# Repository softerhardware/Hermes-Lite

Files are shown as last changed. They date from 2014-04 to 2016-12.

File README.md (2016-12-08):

Hermes-Lite 1.x Deprecated Project!!!
=====================================

This project is deprecated. Current development is now focussed on the Hermes-Lite 2.x. See the main [Hermes-Lite Web Page](http://www.hermeslite.com) for the latest links and details.

## Introduction

The hardware is based on Analog Devices' [AD9866](http://www.analog.com/en/broadband-products/broadband-codecs/ad9866/products/product.html) which is a 12-bit broadband modem mixed signal front end that has been repurposed as a direct down conversion and direct up conversion SDR transceiver covering 0-36 MHz. A hardware prototype has been built and tested that uses a [BeMicro SDK](http://www.arrownac.com/solutions/bemicro-sdk/) FPGA board for DSP processing. The FPGA firmware is a port of the [Hermes SDR](http://openhpsdr.org/wiki/index.php?title=HERMES) project. The ported firmware preserves enough compatibility with the original Hermes SDR so that existing Hermes front-end software may be used with the Hermes-Lite without modification. Initial receive and transmit tests show good performance and appear later in this README. All software and hardware intellectual property is open source. Contributions and derivatives are encouraged. Please follow the standard ["Fork and Pull"](https://help.github.com/articles/using-pull-requests/) model and introduce yourself on [Google Groups](https://groups.google.com/forum/#!forum/hermes-lite).

#### Project Goals
 * 0-30MHz (HF) transceiver with decent performance
 * Entirely open source and open hardware design
 * Cost of less than $150 (cost includes FPGA board) for hobbyist who build their own
 * Maintain enough compatibility with Hermes to use existing Hermes SDR front-end software with no or minor modification

#### Hermes-Lite v1.21
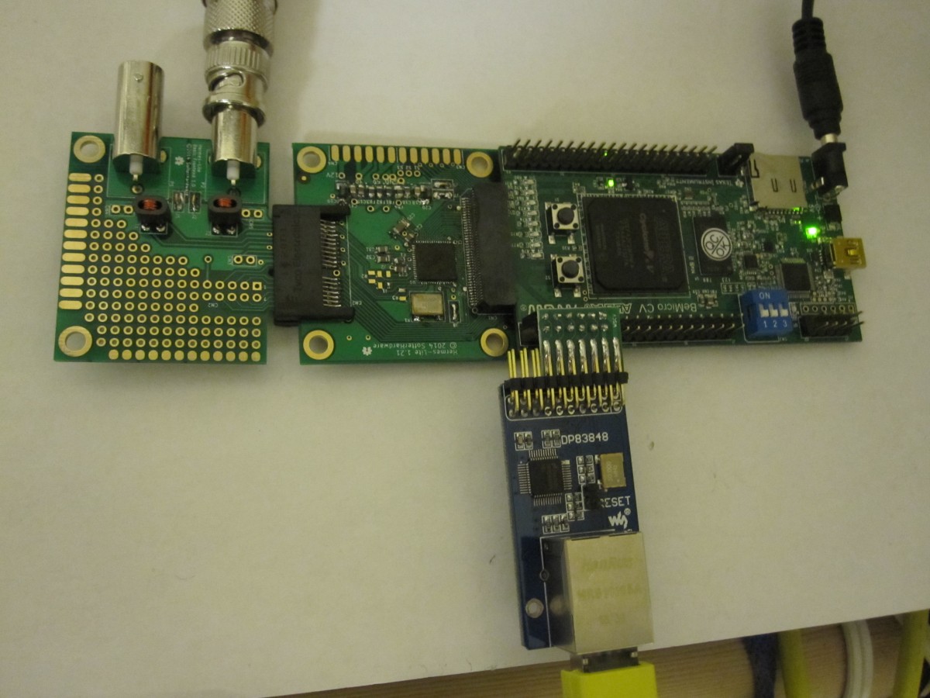
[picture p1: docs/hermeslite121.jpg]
Hermes-Lite121


#### Hermes-Lite v1.2
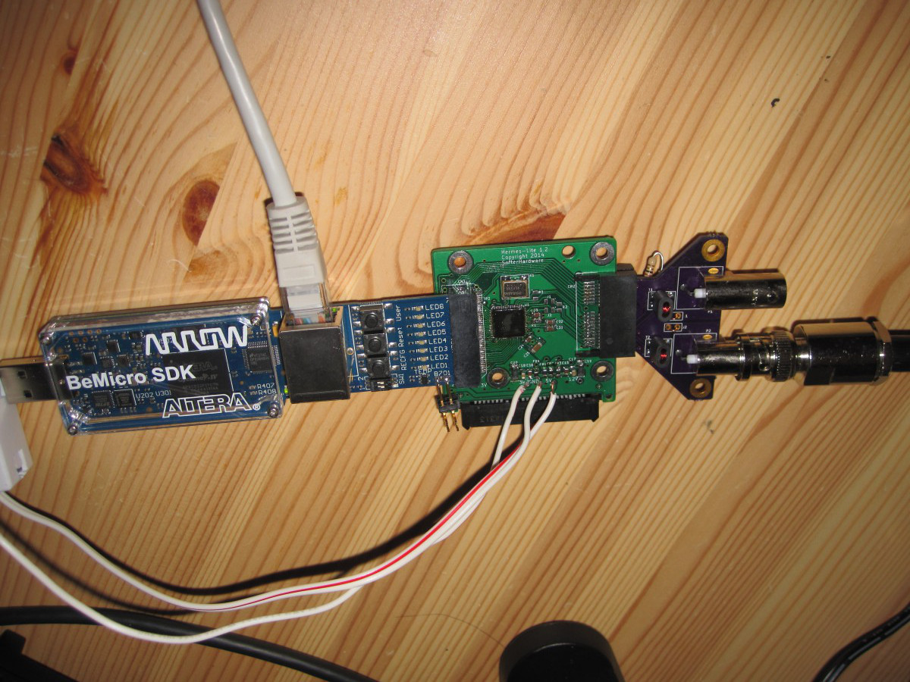
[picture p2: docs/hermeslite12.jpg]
Hermes-Lite12


#### Hermes-Lite v0.9
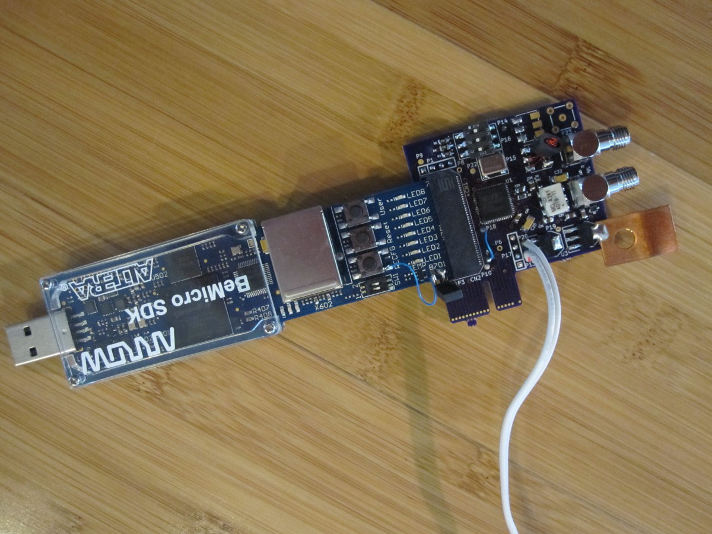
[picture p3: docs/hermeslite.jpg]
Hermes-Lite09


## Receive Experiments

I compared the Hermes-Lite with a Hermes and a [SoftRock RXTX Ensemble Transceiver](http://fivedash.com/) at spotting JT65 and JT9 transmissions with [WSJT-X](http://www.physics.princeton.edu/pulsar/K1JT/wsjtx.html) software running on Linux. I connected two radios to the same antenna right at a tee so there is no additional coax for either radio. I adjusted the radios so that common spots are within a few Hz. This ensures that one radio is not spotting signals that are out of band for the other. I adjusted audio levels to be similar for both copies of WSJT-X that I am running. WSJT-X is not very sensitive to different input levels anyway. The Hermes and Hermes-Lite were both using [ghpsdr-alex](http://napan.ca/ghpsdr3/index.php/Main_Page) software running on separate computers, and the RXTX was using [Quisk](http://james.ahlstrom.name/quisk/). The Hermes has a 4-1 impedance transformer. The Hermes-Lite has a 9-1 impedance transformer to better match the 400 Ohm input of the AD9866. This explains some differences in the data. The Hermes was run with no attenuation and hence has 20 dB gain from the LTC6400-20. The Hermes-Lite was also run with integrated gain set to ~20 dB unless noted otherwise. Finally, I let everything run for several hours to get a large sample set. 

### JT65 and JT9 Spot Data

| Band | 30M | 30M | 30M | 10M | 10M | 10M | 10M | 10M |
|:---- | ---:| ---:| ---:| ---:| ---:| ---:| ---:| ---:|
| Total Spots | 1629  |  676  |  826  |  2421  |  1488  |  1934  |  2461  |  570  |
| Common Spots | 1448 (88.9%)  |  647 (95.7%)  |  792 (95.9%)  |  1680 (69.4%)  |  778 (52.3%)  |  1420 (73.4%)  |  1663 (67.6%)  |  414 (72.6%)  |
| Lite Unique Spots |  |  22 (3.3%)  |  24 (2.9%)  |  |  699 (47.0%)  |  493 (25.5%)  |  768 (31.2%)  |  39 (6.8%)  |
| Hermes Unique Spots |  103 (6.3%)  |  7 (1.0%)  |  10 (1.2%)  |  342 (14.1%)  | |  21 (1.1%)  |  30 (1.2%)  |  117 (20.5%)  |
| RXTX Unique Spots | 78 (4.8%)  | | |  399 (16.5%)  |  11 (0.7%)  | | | |
| Lite Gain dB | | 20  | 28  | | 28  | 20  | 28  | 12  |
| Lite Common SNR Average dB |  |  -8.1 |  -7.7 | | -4.7 |  -9.0  |  -9.1 |  -12.8 |
| Hermes Common SNR Average dB | -7.3 |  -8.0 |  -7.7 |  -6.1 | |  -9.8 |  -10.2 |  -9.6 |
| RXTX Common SNR Average dB |  -7.5 | | |  -10.0 |  -12.6 |  | |  |
| Lite Unique SNR Average dB | |  -11.9 |  -11.5 |  |  -17.3 |  -16.2 |  -14.8 |  -15.5 |
| Hermes Unique SNR Average dB |  -15.3 |  -13.3 |  -20.4 |  -16.9 | |  -16.0 |  -14.2 |  -18.5 |
| RXTX Unique SNR Average dB |  -8.6 | | |  -11.9 |  -12.0 | | | |

The results from the Hermes-Lite compare well with the Hermes and the RXTX. You can see that on 30M all radios were about the same, maybe with a slight edge to the Hermes-Lite on unique spot count. The more interesting data is on 10M. Here there was a clear advantage to the Hermes-Lite in terms of unique spots and SNR (average SNR of all common spots) when the Hermes-Lite was run at 20 dB gain (to match the fixed gain of the Hermes but not accounting for the different input transformers) or 28 dB. When the Hermes-Lite was run with only 12 dB gain, the Hermes did better. This suggests that the Hermes might benefit from additional gain on the higher frequencies.  

When one radio has a unique spot that the other misses, it is not because the other radio missed all spots within that minute. Rather, I see that one radio spots n and the other n-1. The missed spot is not always the weakest signal. Sometimes it is a fairly strong signal. More often the missed spot is a JT9 signal, which has a narrower bandwidth and more stringent demands.

I did not experience problems with exceeding the lower dynamic range of the Hermes-Lite. This may be due in part to my relatively poor antenna setup and rural town location. All experiments were with a ~7M vertical with base at ~2M above ground with a wire grape trellis as a ground plane. The vertical was tuned with a Z-match at the base. Also, the integrated gain in the Hermes-Lite with control in 1 dB steps from -12 dB to +48 dB appears useful to extend the dynamic range. There is a fast path to adjust this gain so that an AGC may be implemented.

These experiments only test a receiver's performance at decoding JT65 and JT9 in the real world, and other proper receiver measurments should be run, but I think they are somewhat indicative of a receiver's performance in general. Even though a less expensive ADC and clock source were used when compared to the Hermes, I did not see any dramatic penalty in reception of JT65 and JT9 spots. Instead, I saw cases where the Hermes-Lite performed better. 

## Transmit Experiments

I tested transmit with [WSPR](http://www.physics.princeton.edu/pulsar/K1JT/wspr.html) and observed spots of my signal on [WSPRnet](http://wsprnet.org/). [PowerSDR](http://openhpsdr.org/wiki/index.php?title=PowerSDR) running under Windows was used to test transmit. At first, I had only 10 dBm (10 mW) output as I had not adjusted the transmit interpolation filter for the new sampling frequency. After adjusting the interpolation filter, I had 17 dBm (50 mW) output. I am using the IAMP on the AD9866 which will do 20 dBm (100 mW) and even 23 dBm (200 mW) with some distortion. I am targeting 20 dBm (100 mW) but need to get a large ferrite core to accomodate the correct turns ratio. The unique WSPR spots appear below. This is just an indicator that transmit is working and proper transmit measurments still must be made. 

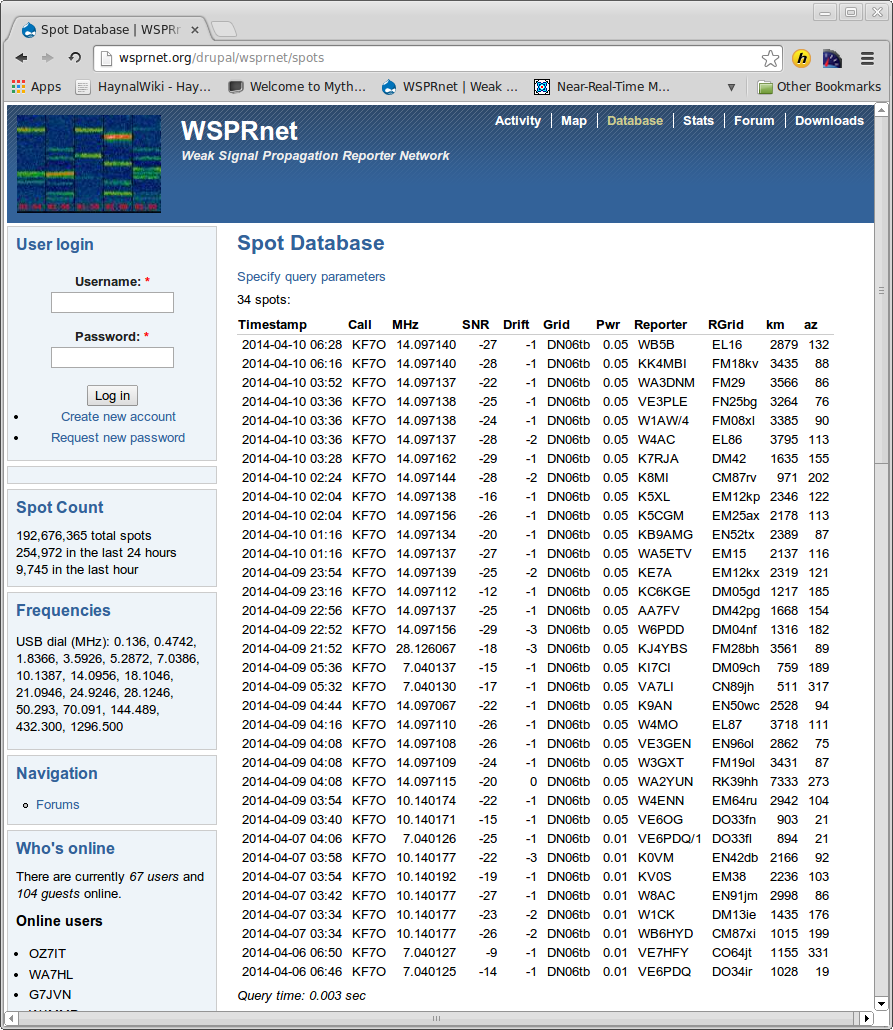
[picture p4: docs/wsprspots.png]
WSPR Spots


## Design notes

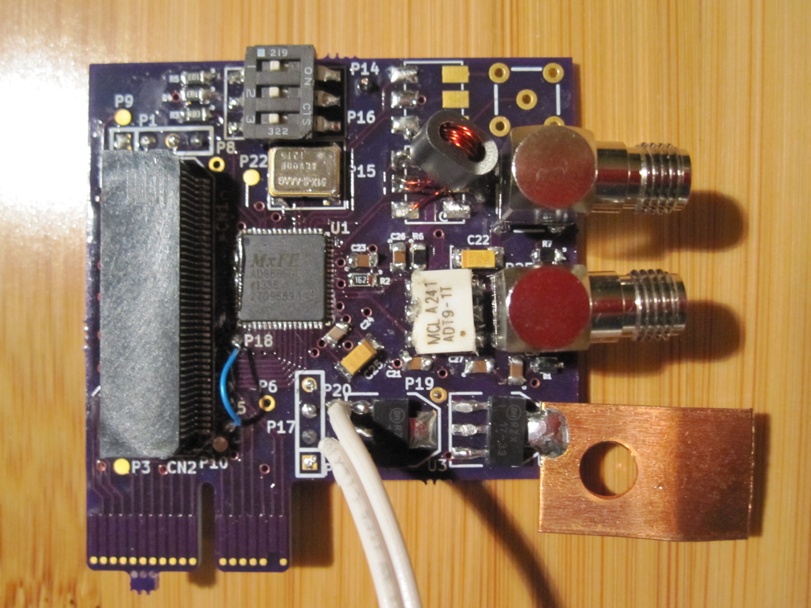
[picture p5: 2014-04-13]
pcb/hermeslite_front.jpg

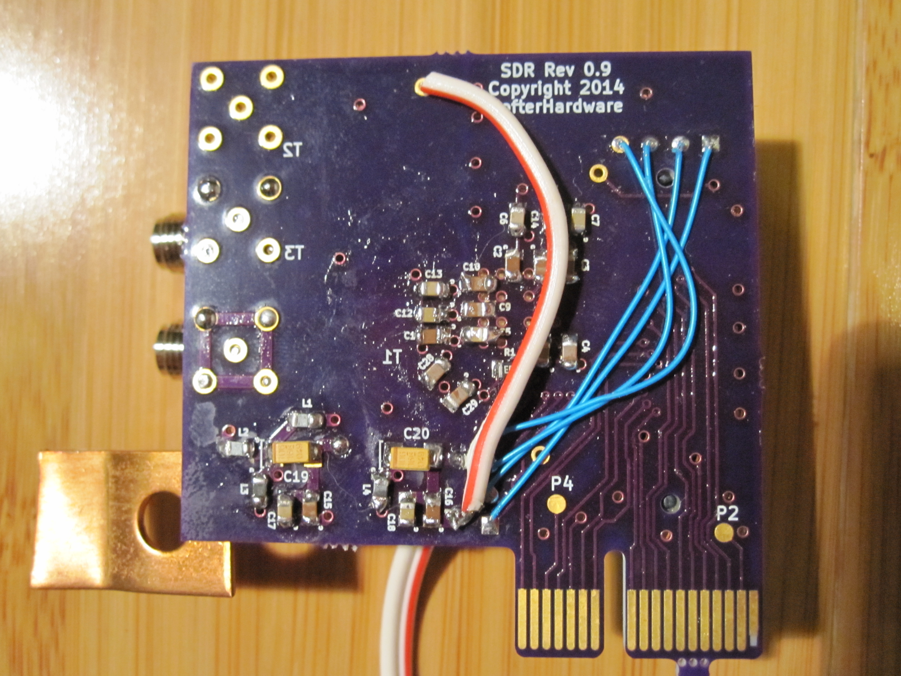
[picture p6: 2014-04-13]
pcb/hermeslite_back.jpg

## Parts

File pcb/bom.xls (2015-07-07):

Line Item | Quantity | Designator | Value/Description | Package | Type | Manufacturer | Manufacturer P/N | Substitution Allowed | Comments | Supplier | Supplier P/N | Supplier Price | Total Price
1 | 1 | U1 | AD9866BCPZ | 64 LFCSP | SMT | Analog Devices | AD9866BCPZ | No |  | Verical | AD9866BCPZ-ND | 27.457 | 27.46
2 | 20 | C1,C2,C3,C4,C9,C10,C11,C15,C16,C22,C23,C24,C28,C29,C31,C32,C33,C34,C35,C36 | 0.1 uF | 0805 | SMT | Yageo | CC0805ZRY5V9BB104 | Yes | Low ESR | Digi-Key | 311-1361-1-ND | 0.022 | 0.44
3 | 13 | C5,C6,C7,C8,C12,C13,C14,C17,C18,C21,C26,C27,C30 | 1 uF | 0805 | SMT | Yageo | CC0805KKX7R7BB105 | Yes | Low ESR | Digi-Key | 311-1365-1-ND | 0.052 | 0.67
4 | 2 | C19,C20 | 10 uF | 1206 | SMT | AVX Corporation | F931A106MAA | Yes | Low ESR | Digi-Key | 478-8193-1-ND | 0.279 | 0.56
5 | 1 | C25 | 10 uF | 1206 | SMT | Kemet | C1206C106Z8VACTU | Yes | Low ESR | Digi-Key | 399-1299-1-ND | 0.132 | 0.13
6 | 8 | FB1,FB2,FB3,FB4,FB5,FB6,FB7,FB8 | Ferrite Chip | 0805 | SMT | TDK Corporation | MPZ2012S221A | Yes |  | Digi-Key | 445-1568-1-ND | 0.101 | 0.81
7 | 1 | X1 | 73.728 Mhz XTAL | 6-SMD | SMT | Silicon Laboratories Inc | 510CCB-AAAG | No | Program to 73.728 Mhz | Digi-Key | 510CCB-AAAG-ND | 4.840 | 4.84
8 | 1 | R1 | 1.6 K | 0805 | SMT | Yageo | RC0805JR-071K6L | Yes |  | Digi-Key | 311-1.6KARCT-ND | 0.018 | 0.02
9 | 2 | J3,J6 | 0 Ohm | 0805 | SMT | Yageo | RC0805JR-070RL | Yes |  | Digi-Key | 311-0.0ARCT-ND | 0.018 | 0.04
10 | 1 | CN1 | BeMicro Connector |  | SMT | Samtec Inc | MEC6-140-02-L-D-RA1 | No |  | Samtec | MEC6-140-02-L-D-RA1 | 6.440 | 6.44
11 | 1 | CN2 | PCIe Connector |  | SMT | Sullins Connector Solutions | GWE18DHRN-T9410 | See Comments | Also TE Connectivity 5-1734857-5 | Digi-Key | S9649-ND | 2.620 | 2.62
12 | 2 | J5, J8 | Copper Wire |  | TH |  |  | Yes |  |  |  | 0.000 | 0.00
13 | 1 | U2 | SPI Serial EEPROM | SOT-23-6 | SMT | Microchip Technology | 25AA02E48T-I/OT | Yes | Optional IP/MAC EEPROM | Digi-Key | 25AA02E48T-I/OTCT-ND | 0.47 | 0.47
14 | 2 | R2,R3 | 200 Ohm | 0805 | SMT | Yageo | RC0805JR-07200RL | Yes | Optional termination | Digi-Key | 311-200ARCT-ND | 0.018 | 0.04
15 | 2 | R4,R5 | 47 Ohm | 0805 | SMT | Yageo | RC0805JR-0747RL | Yes | Optional termination | Digi-Key | 311-47ARCT-ND | 0.018 | 0.04
16 | 3 | J1,J2,J4 | 0 Ohm | 0805 | SMT | Yageo | RC0805JR-070RL | Yes | Optional jumpers | Digi-Key | 311-0.0ARCT-ND | 0.018 | 0.05
17 | 2 | CN3,CN4 | 0.1 DIL Header |  |  |  |  | Yes |  |  |  | 0.000 | 0.00
18 | 1 | J7 | Copper Wire |  |  |  |  | Yes |  |  |  | 0.000 | 0.00
 | 64 |  |  |  |  |  |  |  |  |  |  |  | 44.62
 |  | DO NOT STUFF MARKED IN RED

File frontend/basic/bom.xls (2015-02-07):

Line Item | Quantity | Designator | Value/Description | Package | Type | Manufacturer | Manufacturer P/N | Substitution Allowed | Comments | Supplier | Supplier P/N | Supplier Price | Total Price
1 | 4 | C1,C2,C3,C4 | 0.1 uF | 0805 | SMT | Yageo | CC0805ZRY5V9BB104 | Yes | Low ESR | Digi-Key | 311-1361-1-ND | 0.022 | 0.09
2 | 1 | FB1 | Ferrite Chip | 0805 | SMT | TDK Corporation | MPZ2012S221A | Yes |  | Digi-Key | 445-1568-1-ND | 0.101 | 0.10
3 | 1 | R1 | 0 Ohm | 0805 | SMT | Yageo | RC0805JR-070RL | Yes | Select to limit TX current | Digi-Key | 311-0.0ARCT-ND | 0.018 | 0.02
4 | 1 | D1 | TVS Diode | SOD323 | SMT | Bourns Inc. | CDSOD323-T05LC | See Comments | May adjust to limit peak voltages | Digi-Key | CDSOD323-T05LCCT-ND | 0.910 | 0.91
5 | 2 | T1,T2 | BN-61-2402 |  | TH | Kits and Parts | BN-61-2402 | See Comments | May change to improve balun | Kits and Parts | BN-61-2402 | 0.700 | 1.40
6 | 2 | P1,P2 | BNC Connector | BNC | TH | Molex Inc. | 731000105 | Yes |  | Digi-Key | WM5524-ND | 1.480 | 2.96
7 | 2 | J1,J2 | Copper Wire Jumper |  |  |  |  |  |  |  |  | 0.000 | 0.00
 | 13 |  |  |  |  |  |  |  |  |  |  |  | 5.48

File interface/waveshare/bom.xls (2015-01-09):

Line Item | Quantity | Designator | Value/Description | Package | Type | Manufacturer | Manufacturer P/N | Substitution Allowed | Comments | Supplier | Supplier P/N | Supplier Price | Total Price
1 | 1 | CN1 | 12-pin connector |  | TH | Sullins Connector Solutions | PPTC062LFBN-RC | Yes | Can use 2 6-pin Arduino headers | Digi-Key | S7074-ND | 0.980 | 0.98
 | 1 |  |  |  |  |  |  |  |  |  |  |  | 0.98

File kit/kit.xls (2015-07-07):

Line Item | Quantity | Value/Description | Package | Type | Manufacturer | Manufacturer P/N | Supplier | Supplier P/N | Supplier Price | Total Price | Notes
1 | 25 | 0.1 uF | 0805 | SMT | Yageo | CC0805ZRY5V9BB104 | Digi-Key | 311-1361-1-ND | 0.012 | 0.29
2 | 14 | 1 uF | 0805 | SMT | Yageo | CC0805KKX7R7BB105 | Digi-Key | 311-1365-1-ND | 0.027 | 0.38
3 | 3 | 10 uF | 1206 | SMT | AVX Corporation | F931A106MAA | Digi-Key | 478-8193-1-ND | 0.279 | 0.84
4 | 2 | 10 uF | 1206 | SMT | Kemet | C1206C106Z8VACTU | Digi-Key | 399-1299-1-ND | 0.080 | 0.16
5 | 10 | Ferrite Chip | 0805 | SMT | TDK Corporation | MPZ2012S221A | Digi-Key | 445-1568-1-ND | 0.057 | 0.57
6 | 1 | 73.728 Mhz XTAL | 6-SMD | SMT | Silicon Laboratories Inc | 510CCB-AAAG | Digi-Key | 510CCB-AAAG-ND | 5.570 | 5.57
7 | 2 | 1.6 K | 0805 | SMT | Yageo | RC0805JR-071K6L | Digi-Key | 311-1.6KARCT-ND | 0.013 | 0.03
8 | 7 | 0 Ohm | 0805 | SMT | Yageo | RC0805JR-070RL | Digi-Key | 311-0.0ARCT-ND | 0.007 | 0.05
9 | 1 | PCIe Connector |  | SMT | Sullins Connector Solutions | GWE18DHRN-T9410 | Digi-Key | S9649-ND | 2.620 | 2.62
10 | 1 | SPI Serial EEPROM | SOT-23-6 | SMT | Microchip Technology | 25AA02E48T-I/OT | Digi-Key | 25AA02E48T-I/OTCT-ND | 0.388 | 0.39
11 | 3 | 200 Ohm | 0805 | SMT | Samsung | RC2012J201CS | Digi-Key | 1276-5514-1-ND | 0.015 | 0.05
12 | 5 | 47 Ohm | 0805 | SMT | Yageo | RC0805JR-0747RL | Digi-Key | 311-47ARCT-ND | 0.007 | 0.04
13 | 1 | TVS Diode | SOD323 | SMT | Bourns Inc. | CDSOD323-T05LC | Digi-Key | CDSOD323-T05LCCT-ND | 0.794 | 0.79
14 | 2 | BNC Connector | BNC | TH | Molex Inc. | 731000105 | Digi-Key | WM5524-ND | 1.342 | 2.68
15 | 13 | Shipping and Handling |  |  |  |  |  |  | 8.380 | 0.64
16 | 1 | AD9866BCPZ | 64 LFCSP | SMT | Analog Devices | AD9866BCPZ | Verical | AD9866BCPZ | 27.457 | 27.46
17 | 13 | Shipping and Handling |  |  |  |  |  |  | 19.040 | 1.46
18 | 1 | BeMicro Connector |  | SMT | Samtec Inc | MEC6-140-02-L-D-RA1 | Samtec | MEC6-140-02-L-D-RA1 | 6.440 | 6.44
19 | 13 | Shipping and Handling |  |  |  |  |  |  | 25.000 | 1.92
20 | 2 | BN-43-2402 |  | TH | Kits and Parts | BN-61-2402 | Kits and Parts | BN-61-2402 | 0.280 | 0.56
21 | 13 | Shipping and Handling |  |  |  |  |  |  | 4.330 | 0.33
22 | 1 | Hermes-Lite PCB |  |  | Elecrow |  | Elecrow |  | 2.614 | 2.61
23 | 1 | Basic Frontend PCB |  |  | Elecrow |  | Elecrow |  | 1.108 | 1.11
24 | 1 | Waveshare Swizzle PCB |  |  | Elecrow |  | Elecrow |  | 0.478 | 0.48
25 | 50 | Shipping and Handling |  |  |  |  |  |  | 31.590 | 0.63
26 | 1 | Assembly |  |  | Zelpro Solutions |  |  |  | 26.000 | 26.00
27 |  | Shipping and Handling |  |  |  |  |  |  | 0.000 | 0.00
28 | 1 | Packing Material |  |  | Aviditi | M432 | Amazon |  | 0.241 | 0.24
29 |  | Shipping and Handling |  |  |  |  |  |  | 0.000 | 0.00
30 | 1 | Kitting, Packaging, Mailing |  |  |  |  |  | Son | 5.000 | 5.00
31 | 1 | Margin |  |  |  |  |  |  | 15.000 | 15.00
32 | 1 | Financial fees |  |  |  |  |  | PayPal | 3.250 | 3.25 | Estimate
 |  |  |  |  |  |  |  |  |  | 107.61 | Total
 | 1 | Domestic First Class |  |  |  |  |  |  | 3.00 |  | Estimate
 | 1 | Priority Flat Rate |  |  |  |  |  |  | 5.95
 | 1 | International First Class |  |  |  |  |  |  | 13.00 |  | Estimate
 | 1 | International Priority Flat Rate |  |  |  |  |  |  | 24.75

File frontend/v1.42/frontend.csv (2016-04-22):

Quantity | Package | Value | Reference | Notes | Digikey
1 | BREAKOUT14 | RELAYCNT14 | CN2 | 2X7 0.1 inch pin header
9 | C_0805_HandSoldering | 100n | C9 C10 C7 C8 C5 C6 C12 C14 C15 | ceramic
2 | C_0805_HandSoldering | 120p | C18 | 5.00%
2 | C_0805_HandSoldering | 150p | C2 C16 | 5.00%
1 | C_0805_HandSoldering | 160p | C3 | 5.00%
2 | C_0805_HandSoldering | 100p | C4 C11 C17 | 5.00%
1 | C_0805_HandSoldering | 180p | C16 | 5.00%
1 | C_0805_HandSoldering | 75p | C1 | 5.00%
1 | C_0805_HandSoldering | FB | FB2 | Ferite chip, MPZ2012S221A | 445-15-1-ND
1 | EDGE | EDGE | CN1
6 | Measurement_Point_Round-TH_Small | TST | P7 P8 P5 P6 P10 P4
1 | PINHEAD1-2 | 12V | P1 | 2X1 0.1 inch pin header for 12 volt power (only needed if no 12V on main board)
1 | PSOP-18 | ULN2803 | U6 | Texas Instruments darlington array
1 | R_0805_HandSoldering | 10k | R3
2 | R_0805_HandSoldering | 1200 | R10 R15
2 | R_0805_HandSoldering | 22 | R12 R13
2 | R_0805_HandSoldering | 1000 | R5 R18
2 | R_0805_HandSoldering | 2200 | R9 R11
2 | R_0805_HandSoldering | 24 1/4W | R7 R8 | Panasonic ERJ-P06J240V, Output resistors need ¼ W or more for higher power designs | P24ADCT-ND
2 | R_0805_HandSoldering | 240n | L1 L2 | 240n inductor 0806, Murata air wound 5% LQW2BASR24J00L | 490-5670-1-ND
4 | R_0805_HandSoldering | 270n | L3 L6 L7 L8 | 270n inductor 0806, Murata air wound 5% LQW2BASR27J00L | 490-5671-1-ND
2 | R_0805_HandSoldering | 330n | L4 L5 | 330n inductor 0806, Murata air wound 5% LQW2BASR33J00L | 490-5672-1-ND
2 | R_0805_HandSoldering | 33 1% | R1 R2
2 | R_0805_HandSoldering | 330 1% | R14 R16
1 | R_0805_HandSoldering | 75 1% | R6
1 | R_0805_HandSoldering | 560 | R4
1 | SOD-123 | BZT52B12 | D2 | Zener diode SOD-123, 12 volt 5 %
1 | SOD323 | DIODESCH2 | D1 | TVS diode, CDSOD323-T05LC | CDSOD323-T05LCT-ND
1 | SOIC-8-N-PAD | OPA2674 | U3 | dual op amp, current feedback, SOIC-8, or substitute OPA2677 for higher power
1 | SOT89-3_Housing | FCX690B | Q1 | NPN transistor in SOT-89, high beta (200 - 300) preferred, but any will work
1 | TantalC_SizeT_EIA-3528 | 10u | C13 | Tantalum capacitor, 3528 metric, 20 volts
1 | TransfBN2402 | 1:1 | T2 | BN-43-2402 four turns bifilar (use more turns for BN-61-2402)
1 | TransfBN2402 | 8:1Z | T1 | MABA-010143-FLUX18 or homebrew (see 1.2 frontend)
1 | pe4259 | PE4259 | U2 | RF switch for transmit/receive to single SMA (optional; otherwise jumper P5 to P8, and P6 to P7) | 1046-1011-2-ND
2 | rfconnectorB | SMA/BNC/HDR | P2 P3 | SMA RF connector
 |  |  |  | Build Option 1. On-Board T/R switch: Mount PE4259 and P2 (antenna). Omit P3.
 |  |  |  | Build Option 2. Separate Rfin and Rfout: Mount P2 and P3. Omit PE4259. Jumper P5 to P8 and P6 to P7.
 |  |  |  | Build Option 3: There are different filter designs available on the Hermes-Lite group.
 |  |  |  | Build Option 4: Reduce R7 and R8 for higher power. See frontend.html.
 |  |  |  | Build Option 5: Replace the OPA2674 with the OPA2677 package PSO-8 for higher power output
 |  |  |  | The Tx filter design is by Claudio, IN3OTD / DK1CG
 |  |  |  | The Rx filter design is by Andrew, G4XZL

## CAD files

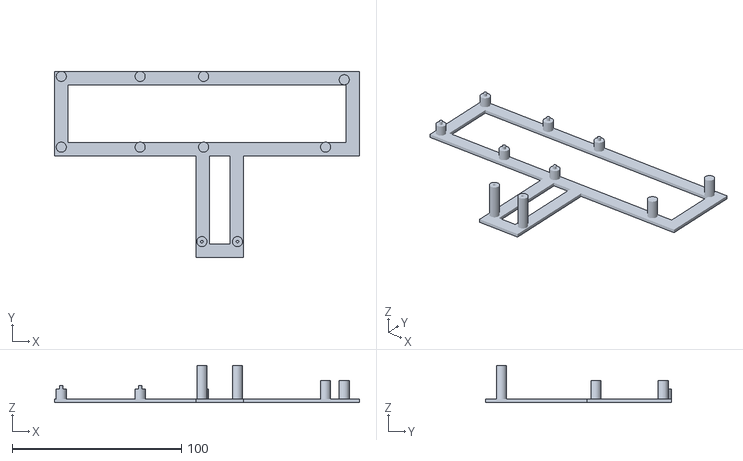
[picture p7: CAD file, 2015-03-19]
3Dprinter/hermes_lite_v2/hermes_lite_v2.stl
180.0 x 110.0 x 22.0

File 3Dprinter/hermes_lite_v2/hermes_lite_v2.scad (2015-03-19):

// main board size
L = 50;
W = 180;
T = 2;

// waveshare size, offset
Lw = 60;
Ww = 28;
Xw = 97.5;
ww = 21;
yw = 50.5;

B = 8;

// spacer heights
S1 = 6;
S2 = 11;
S3 = 20;
Ph = 2;

// spacer radii
Sr = 3;
Pr = 1.0;
Hr = 0.8;
$fn = 30;


module s1()
{
   cylinder(S1, r1=Sr, r2=Sr);
   translate([0,0,S1]) cylinder(Ph, r1=Pr, r2=Pr);
}

module s2()
{
   cylinder(S2, r1=Sr, r2=Sr);
}

module s3()
{
   difference() {
     cylinder(S3, r1=Sr, r2=Sr);
     translate ([0,0,3*S3/4]) cylinder(S3, r1=Hr, r2=Hr);
  }
}

module hermes_lite()

{

 difference() {
     cube([W,L,T]);
     translate ([B,B,0]) cube([W-2*B,L-2*B,T]);
 }
 difference() {
     translate ([Xw-Ww/2,-Lw,0]) cube([Ww,Lw,T]);
     translate ([Xw-Ww/2+B,-Lw+B,0]) cube([Ww-2*B,Lw-B,T]);
 }
 translate ([4,5.25,T] ) s1();
 translate ([4,47,T] ) s1();
 translate ([50.56,5.25,T] ) s1();
 translate ([50.56,47,T] ) s1();
 translate ([88,5.25,T] ) s1();
 translate ([88,47,T] ) s1();
 translate ([160,5.25,T]) s2();
 translate ([171,45,T]) s2();
 translate ([Xw-ww/2,-yw,T]) s3();
 translate ([Xw+ww/2,-yw,T]) s3();
}

hermes_lite();

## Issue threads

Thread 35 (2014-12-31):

Firmware: No 384kHz with new 61.44MHz crystal

softerhardware, 2014-12-31:
Hermes-Lite v1.2 and on use a 61.44MHz crystal for compatibility with future OpenHPSDR projects. Unfortunately, there is no simple divisor down to 384kHz for this frequency. The number of CIC filter decimation steps needs to be adjusted to support 384kHz

softerhardware, 2015-01-17:
Fixed in 20150115 release.

Closed 2015-01-17.

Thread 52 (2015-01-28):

Firmware: Software overload and ADC overload don't match

softerhardware, 2015-01-28:
See New Firmware 20150125 Released thread  on Google Groups.

softerhardware, 2015-03-09:
Fixed

Closed 2015-03-09.

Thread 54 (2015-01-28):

Firmware: AD9866 LPF hooked up to ALEX or J16 settings

softerhardware, 2015-01-28:

AC9HY, 2015-01-28:
Both of my amps have BPF or LPF on transmit. Since we have been seeing issues on the higher frequencies, I intend to built the first superband for 10/12 and 15/17 BPFs as the 2 pairs of bands. Will post info on the mailing list with progress. The Megaboard has a different TX filter config using LPFs. Progress on that board will be slower. Anyone can take the parameters for the 10M LPF from the current schematic and build a filter. I have enough spare components to be able to build one on a protoboard and send it to anyone that can test with it. Let me know.

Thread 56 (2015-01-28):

Firmware: Check Frequency Calibration/Computation

softerhardware, 2015-01-28:
There may have been a fix since I forked from 2.5a for this.

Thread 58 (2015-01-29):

Firmware: Noise floor numbers with 50 Ohm on RX are very different from v1.2

softerhardware, 2015-01-29:
This is due to gain changes when adjusting the filter stages.

softerhardware, 2015-03-09:
This is due to change in gain to match PowerSDR expectations.

Closed 2015-03-09.

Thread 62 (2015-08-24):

V2PA: Investigate heat sink options for enclosure.

AC9HY, 2015-08-24:

in3otd, 2015-12-10:
As briefly discussed [here] (https://groups.google.com/d/msg/hermes-lite/Zywnfl9dglg/Wk3YJk9QAgAJ) , Heatsink USA has a [4.23" wide heatsink] (http://www.heatsinkusa.com/4-230-wide-extruded-aluminum-heatsink/) that could be used in place of the end plate for the [proposed v2.0 enclosure] (https://github.com/softerhardware/Hermes-Lite/wiki/Hermes-Lite-2.0#form-factor-and-pcb) (the enclosure is approx. 4.27" wide). The holes for the fixing screws should end up nicely in the space between the fins.

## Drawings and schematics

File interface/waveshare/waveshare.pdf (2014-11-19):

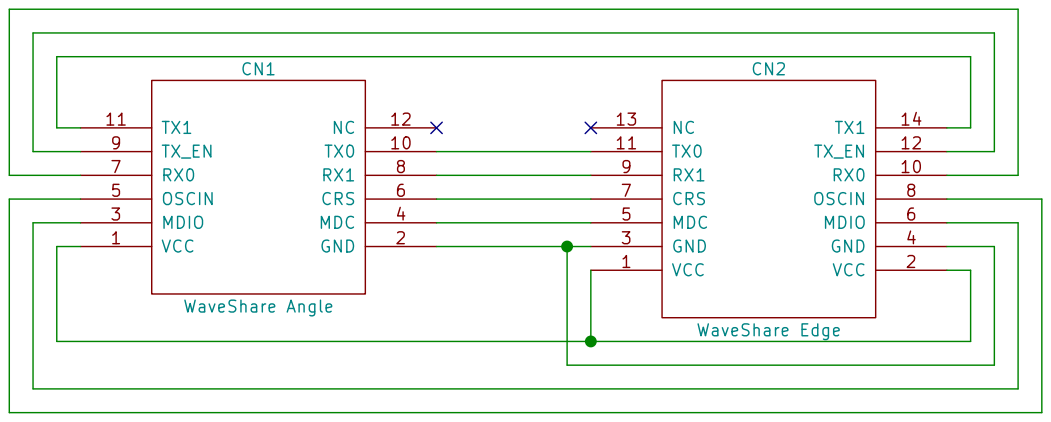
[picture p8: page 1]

File: waveshare.sch Sheet: / SofterHardware KF7O

Id: 1/1 Title: WaveShare Swizzle Board

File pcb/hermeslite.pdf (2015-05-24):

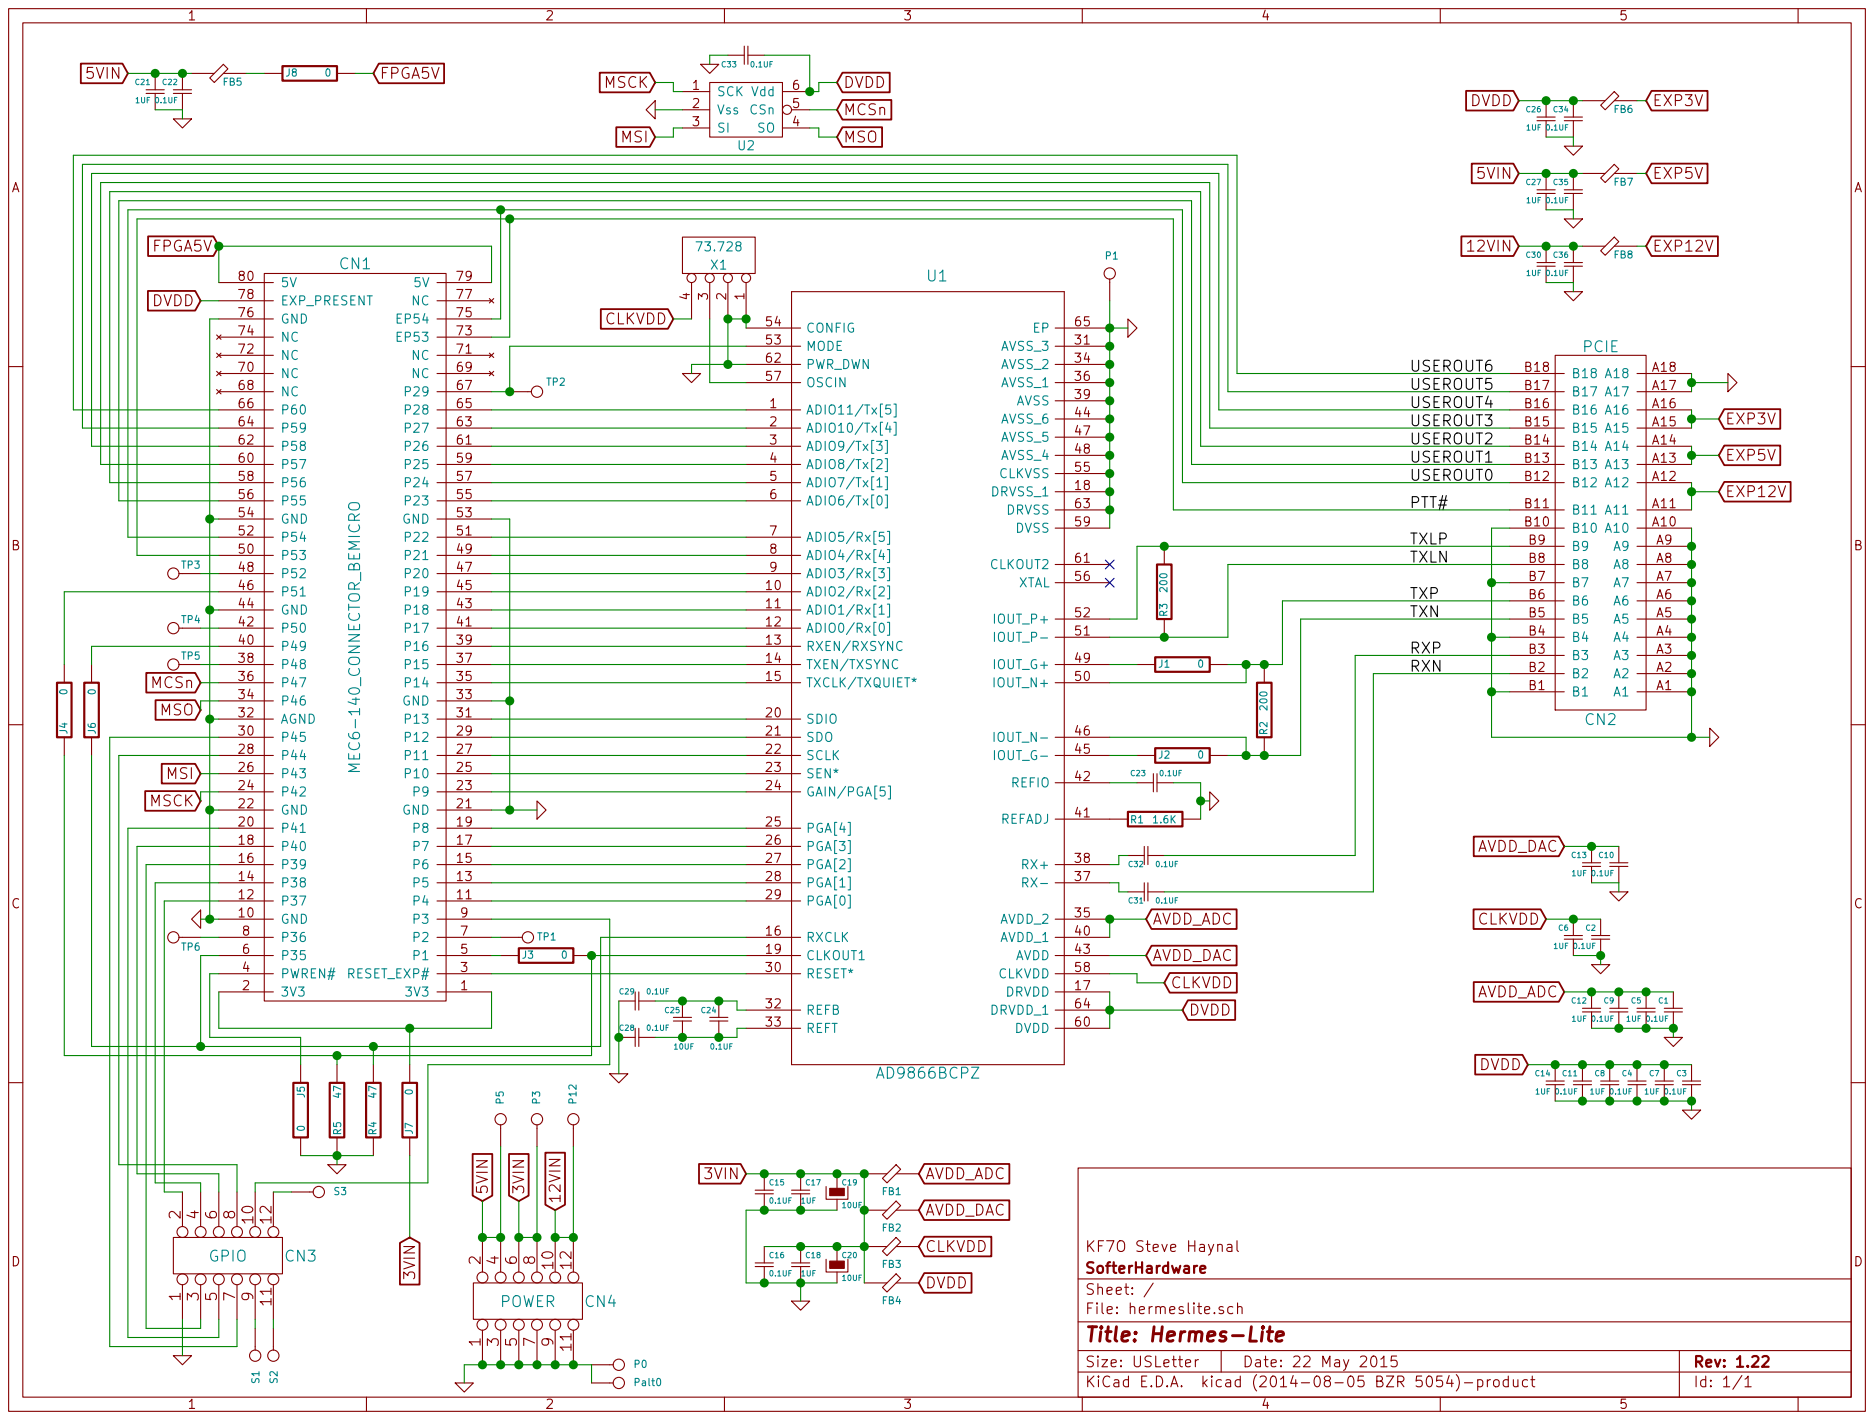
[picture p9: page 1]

File: hermeslite.sch Sheet: / SofterHardware KF7O Steve Haynal DVDD

Id: 1/1 Title: Hermes-Lite

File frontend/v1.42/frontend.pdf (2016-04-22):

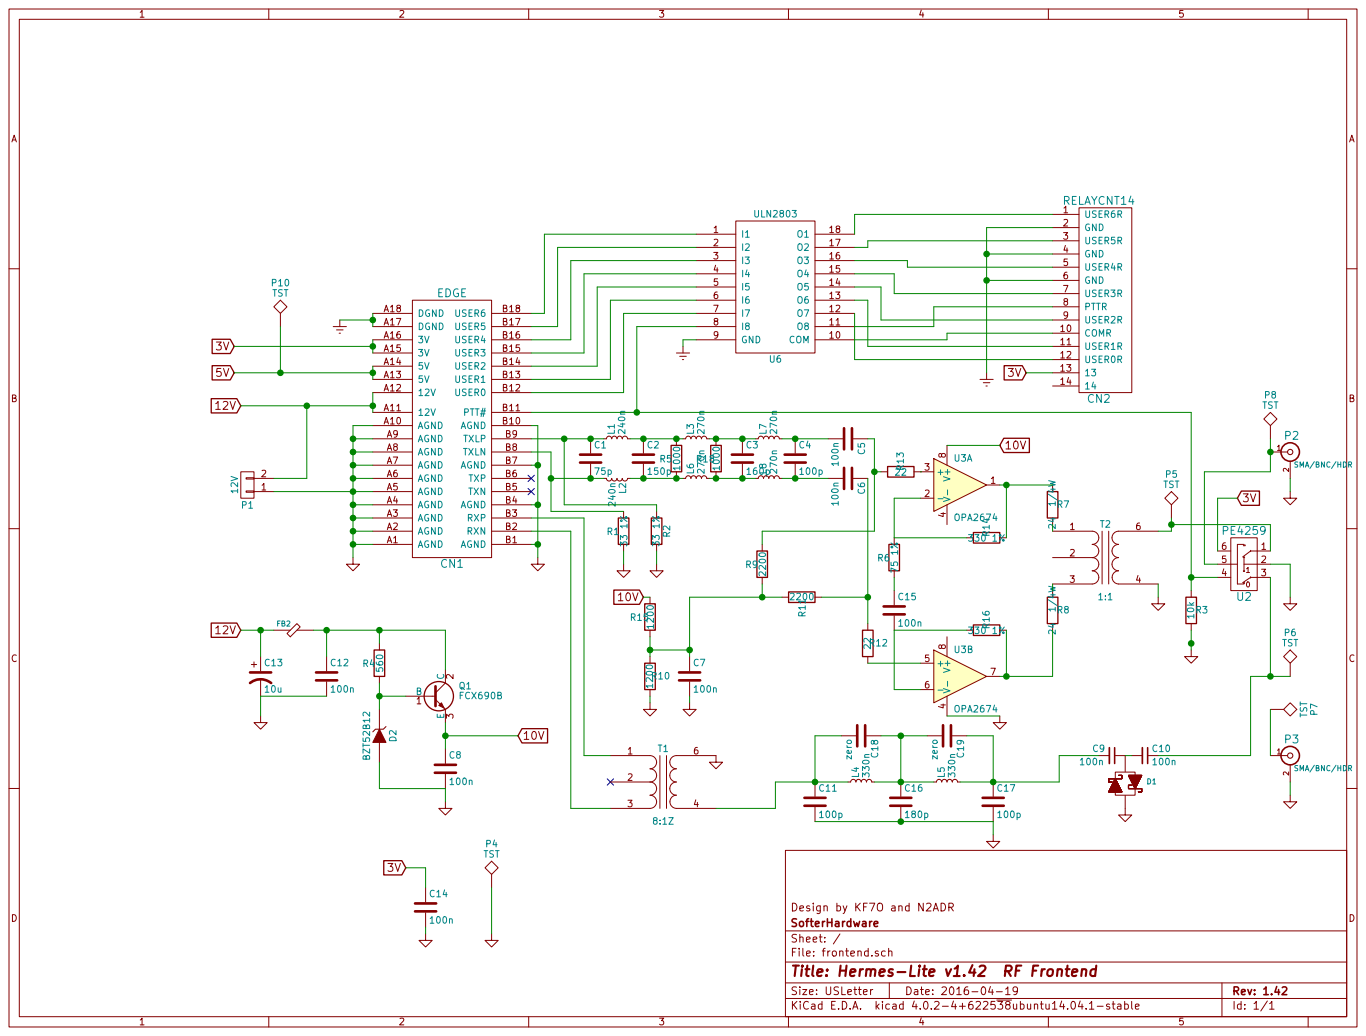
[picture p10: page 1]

File: frontend.sch Sheet: / SofterHardware Design by KF7O and N2ADR

Id: 1/1 Title: Hermes-Lite v1.42 RF Frontend

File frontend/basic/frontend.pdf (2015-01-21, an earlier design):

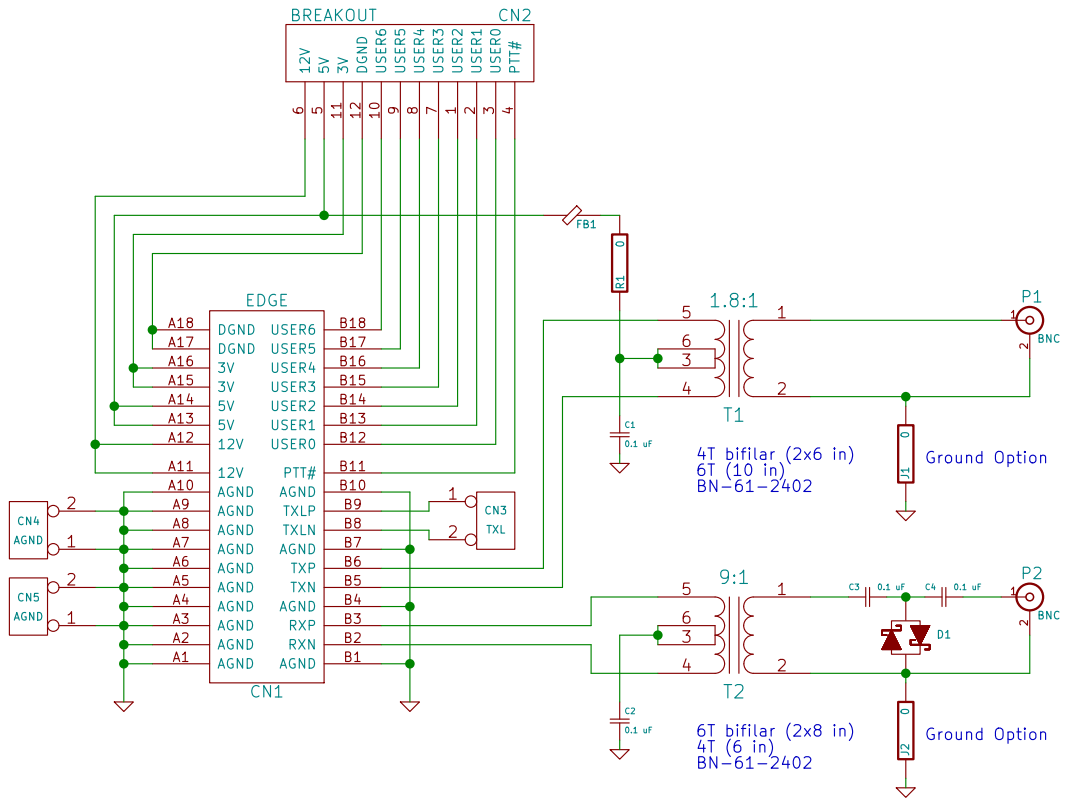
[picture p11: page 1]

File: frontend.sch Sheet: / SofterHardware KF7O

Id: 1/1 Title: Basic Hermes-Lite RF Frontend

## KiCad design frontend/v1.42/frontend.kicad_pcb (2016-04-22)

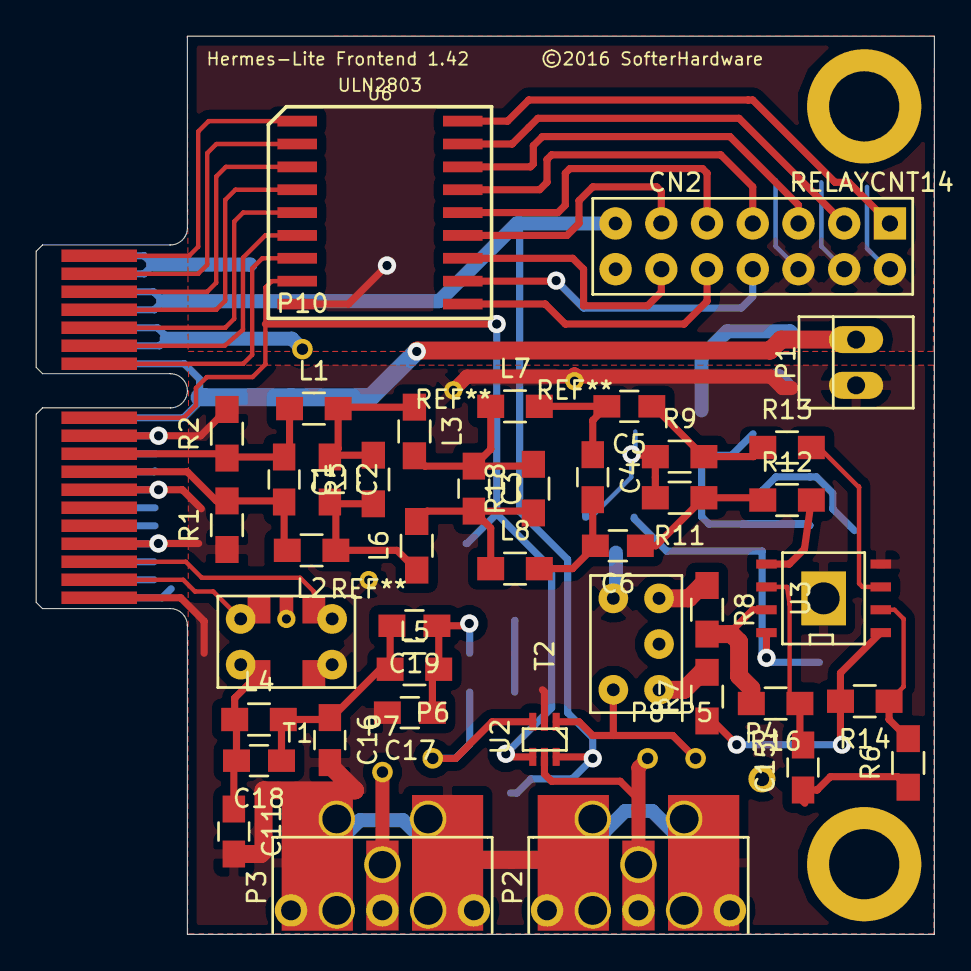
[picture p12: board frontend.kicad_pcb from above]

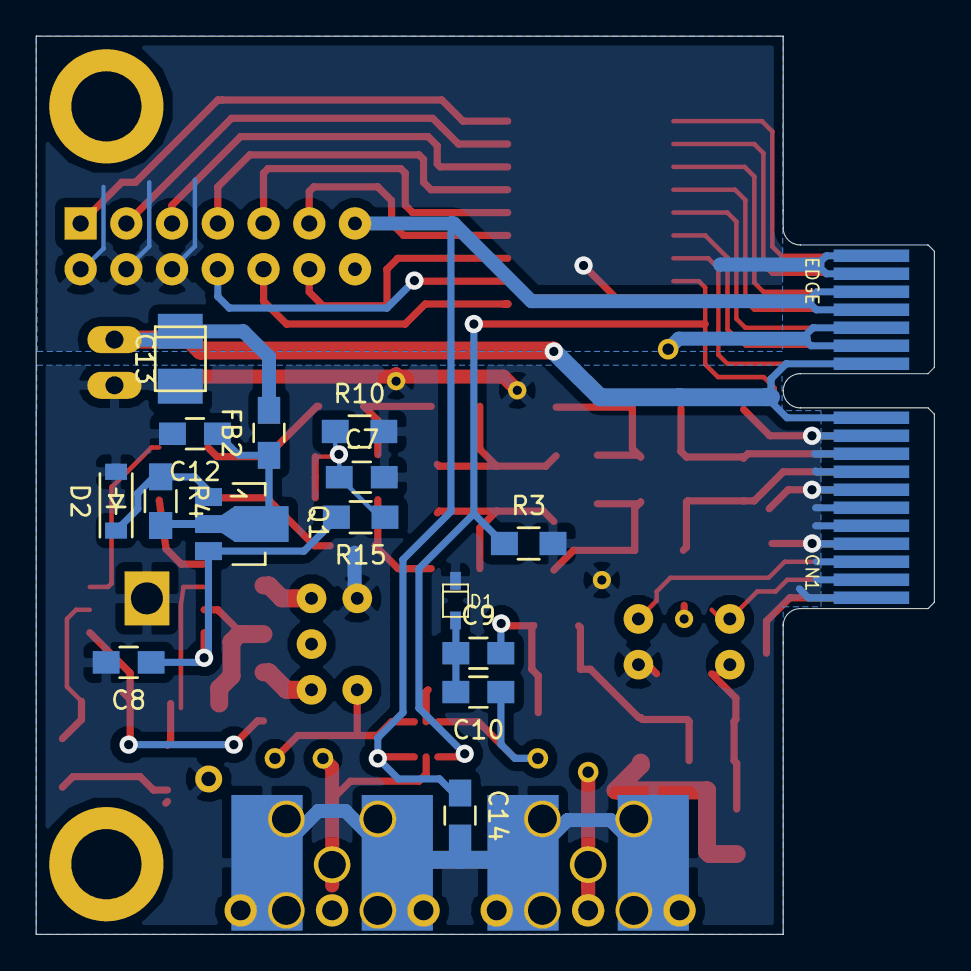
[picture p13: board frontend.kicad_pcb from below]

Board: 2 copper layers, 49.9 x 49.9 mm, 66 parts (16 on the bottom side), 55 nets.

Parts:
C1: 75p; C_0805_HandSoldering
C2: 150p; C_0805_HandSoldering
C3: 160p; C_0805_HandSoldering
C4, C11, C17: 100p; C_0805_HandSoldering
C5, C6, C7, C8, C9, C10, C12, C14, C15: 100n; C_0805_HandSoldering
C13: 10u; TantalC_SizeT_EIA-3528
C16: 180p; C_0805_HandSoldering
C18, C19: zero; C_0805_HandSoldering
CN1: EDGE
CN2: RELAYCNT14; BREAKOUT14
D1: DIODESCH2; SOD323
D2: BZT52B12; SOD-123
FB2: FB; C_0805_HandSoldering
L1, L2: 240n; R_0805_HandSoldering
L3, L6, L7, L8: 270n; R_0805_HandSoldering
L4, L5: 330n; R_0805_HandSoldering
MH: VAL**; MH
MH#2: VAL**; MH
P1: 12V; PINHEAD1-2
P2, P3: SMA/BNC/HDR; rfconnectorB
P4, P5, P6, P7, P8, P10: TST; Measurement_Point_Round-TH_Small
Q1: FCX690B; SOT89-3_Housing
R1, R2: 33 1%; R_0805_HandSoldering
R3: 10k; R_0805_HandSoldering
R4: 560; R_0805_HandSoldering
R5, R18: 1000; R_0805_HandSoldering
R6: 75 1%; R_0805_HandSoldering
R7, R8: 24 1/4W; R_0805_HandSoldering
R9, R11: 2200; R_0805_HandSoldering
R10, R15: 1200; R_0805_HandSoldering
R12, R13: 22; R_0805_HandSoldering
R14, R16: 330 1%; R_0805_HandSoldering
T1: 8:1Z; TransfBN2402
T2: 1:1; TransfBN2402
U2: PE4259; pe4259
U3: OPA2674; SOIC-8-N-PAD
U6: ULN2803; PSOP-18

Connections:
3V: C14.1, CN1.A15, CN1.A16, CN2.13, U2.6
5V: CN1.A13, CN1.A14, P10.1
10V: C8.1, Q1.3, R15.2, U3.8
12V: C13.1, CN1.A11, CN1.A12, FB2.2, P1.2
GND: C7.2, C8.2, C11.2, C12.2, C13.2, C14.2, C16.2, C17.2, CN1.A1, CN1.A2, CN1.A3, CN1.A4, CN1.A5, CN1.A6, CN1.A7, CN1.A8, CN1.A9, CN1.A10, CN1.B1, CN1.B4, CN1.B7, CN1.B10, D1.2, D2.2, P1.1, P2.2, P3.2, P4.1, R1.1, R2.2, R3.2, R10.2, T1.6, T2.4, U2.2, U3.4
GNDREF: CN1.A17, CN1.A18, CN2.2, CN2.4, CN2.6, U6.9
unnamed: C1.1, CN1.B9, L1.1, R2.1
unnamed: C1.2, CN1.B8, L2.2, R1.2
unnamed: C2.1, L1.2, L3.1, R5.2
unnamed: C2.2, L2.1, L6.1, R5.1
unnamed: C3.1, L3.2, L7.1, R18.2
unnamed: C3.2, L6.2, L8.1, R18.1
unnamed: C4.1, C5.2, L7.2
unnamed: C4.2, C6.2, L8.2
unnamed: C5.1, R9.2, R13.1
unnamed: C6.1, R11.1, R12.1
unnamed: C7.1, R9.1, R10.1, R11.2, R15.1
unnamed: C10.1, P6.1, U2.3
unnamed: C9.1, C10.2, D1.1
unnamed: C11.1, C18.2, L4.1, T1.4
unnamed: C12.1, FB2.1, Q1.2, R4.2
unnamed: C15.1, R6.1
unnamed: C15.2, R16.1, U3.6
unnamed: C16.1, C18.1, C19.2, L4.2, L5.1
unnamed: C9.2, C17.1, C19.1, L5.2
unnamed: CN1.B2, T1.3
unnamed: CN1.B3, T1.1
unnamed: CN1.B11, R3.1, U2.4, U6.8
unnamed: CN1.B12, U6.7
unnamed: CN1.B13, U6.6
unnamed: CN1.B14, U6.5
unnamed: CN1.B15, U6.4
unnamed: CN1.B16, U6.3
unnamed: CN1.B17, U6.2
unnamed: CN1.B18, U6.1
unnamed: CN2.1, U6.18
unnamed: CN2.3, U6.17
unnamed: CN2.5, U6.16
unnamed: CN2.7, U6.15
unnamed: CN2.8, U6.11
unnamed: CN2.9, U6.14
unnamed: CN2.10, U6.10
unnamed: CN2.11, U6.13
unnamed: CN2.12, U6.12
unnamed: D2.1, Q1.1, R4.1
unnamed: P2.1, P8.1, U2.5
unnamed: P3.1, P7.1
unnamed: P5.1, T2.6, U2.1
unnamed: R7.2, T2.1
unnamed: R8.1, T2.3
unnamed: R12.2, U3.5
unnamed: R13.2, U3.3
unnamed: R6.2, R14.1, U3.2
unnamed: R7.1, R14.2, U3.1
unnamed: R8.2, R16.2, U3.7

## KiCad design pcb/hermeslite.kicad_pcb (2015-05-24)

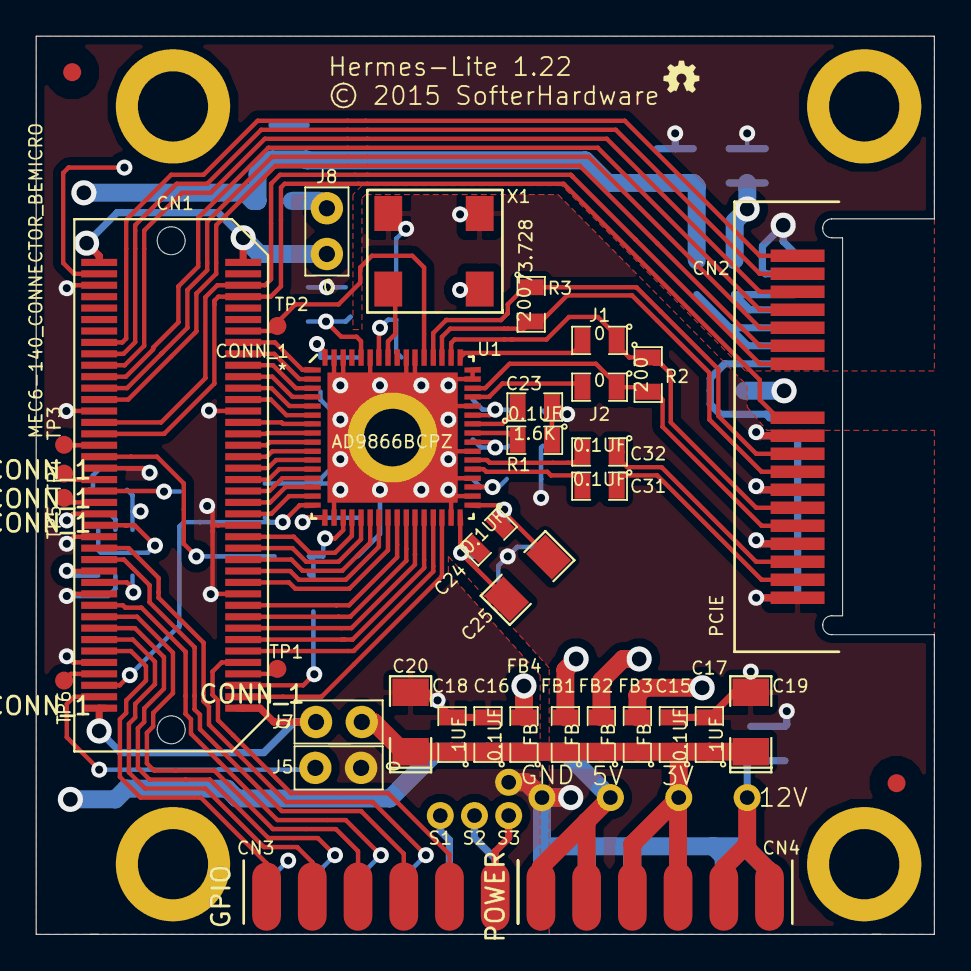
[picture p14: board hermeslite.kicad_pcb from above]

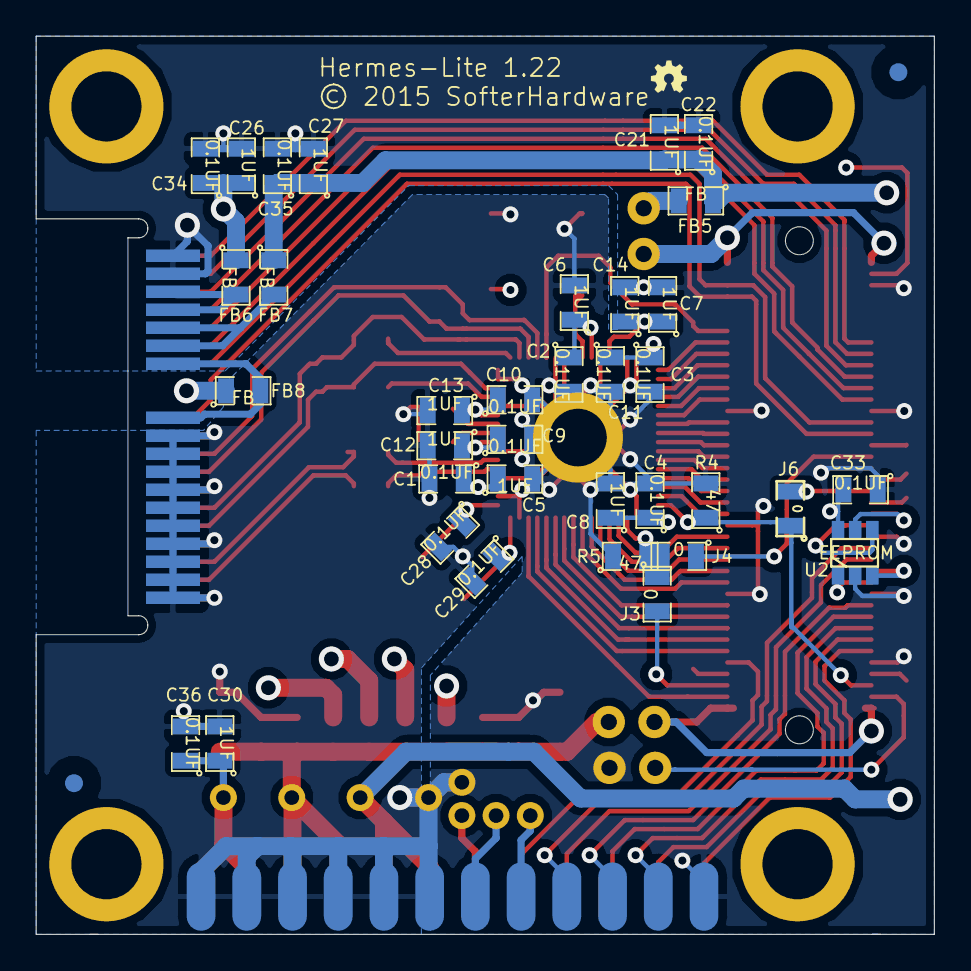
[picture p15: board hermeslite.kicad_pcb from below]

Board: 4 copper layers, 49.9 x 49.9 mm, 87 parts (37 on the bottom side), 90 nets.

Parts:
C1, C2, C3, C4, C9, C10, C11, C23, C24, C28, C29: 0.1UF; SM0805
C5, C6, C7, C8, C12, C13, C14: 1UF; SM0805
C15, C16, C22, C31, C32, C33, C34, C35, C36: 0.1UF; SMD-0805
C17, C18, C21, C26, C27, C30: 1UF; SMD-0805
C19, C20: 10UF; SMD-1206_Pol
C25: 10UF; SM1206
CN1: MEC6-140_CONNECTOR_BEMICRO; MEC6-140-02-X-D-RAX
CN2: PCIE; PCIESTRADDLE
CN3: GPIO; EDGE6
CN4: POWER; EDGE6
FB1, FB2, FB3, FB4, FB5, FB6, FB7, FB8: FB; SMD-0805
FIDUCIAL: VAL**; FIDUCIAL
FIDUCIAL#2, FIDUCIAL#3, FIDUCIAL#4: VAL**; FIDUCIAL
J1, J2, J3, J4, J6: 0; SMD-0805
J5, J7, J8: 0; JUMPER
MH: VAL**; MH
MH#2, MH#3, MH#4: VAL**; MH
P0, P3, P5, P12: CONN_1; Measurement_Point_Round-TH_Small
P1: CONN_1; TH
Palt0: CONN_1; Measurement_Point_Round-TH_Small
R1: 1.6K; SM0805
R2, R3: 200; SMD-0805
R4, R5: 47; SMD-0805
S1, S2, S3: CONN_1; Measurement_Point_Round-TH_Small
TP1, TP2, TP3, TP4, TP5, TP6: CONN_1; TP
U1: AD9866BCPZ; CP_64_3-M
U2: EEPROM; SOT-23-6
X1: 73.728; Si510

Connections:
3VIN: C15.1, C16.1, C17.1, C18.1, C19.1, C20.1, CN4.6, CN4.8, FB1.1, FB2.1, FB3.1, FB4.1, J7.2, P3.1
5VIN: C21.1, C22.1, C27.1, C35.1, CN4.2, CN4.4, FB5.1, FB7.1, P5.1
12VIN: C30.1, C36.1, CN4.10, CN4.12, FB8.1, P12.1
/PTT#: CN1.50, CN1.73, CN2.B11
/RXN: C31.1, CN2.B2
/RXP: C32.1, CN2.B3
/TXLN: CN2.B8, R3.2, U1.51
/TXLP: CN2.B9, R3.1, U1.52
/TXN: CN2.B5, J2.1, R2.2, U1.46
/TXP: CN2.B6, J1.1, R2.1, U1.50
/USEROUT0: CN1.52, CN1.75, CN2.B12
/USEROUT1: CN1.56, CN2.B13
/USEROUT2: CN1.58, CN2.B14
/USEROUT3: CN1.60, CN2.B15
/USEROUT4: CN1.62, CN2.B16
/USEROUT5: CN1.64, CN2.B17
/USEROUT6: CN1.66, CN2.B18
AVDD_ADC: C1.1, C5.1, C9.1, C12.1, FB1.2, U1.35, U1.40
AVDD_DAC: C10.1, C13.1, FB2.2, U1.43
CLKVDD: C2.1, C6.1, FB3.2, U1.58, X1.4
DVDD: C3.1, C4.1, C7.1, C8.1, C11.1, C14.1, C26.1, C33.2, C34.1, CN1.78, FB4.2, FB6.1, U1.17, U1.60, U1.64, U2.6
EXP3V: CN2.A15, CN2.A16, FB6.2
EXP5V: CN2.A13, CN2.A14, FB7.2
EXP12V: CN2.A11, CN2.A12, FB8.2
FPGA5V: CN1.79, CN1.80, J8.1
GND: C1.2, C2.2, C3.2, C4.2, C5.2, C6.2, C7.2, C8.2, C9.2, C10.2, C11.2, C12.2, C13.2, C14.2, C15.2, C16.2, C17.2, C18.2, C19.2, C20.2, C21.2, C22.2, C23.2, C26.2, C27.2, C28.2, C29.2, C30.2, C33.1, C34.2, C35.2, C36.2, CN1.10, CN1.21, CN1.22, CN1.32, CN1.33, CN1.44, CN1.53, CN1.54, CN1.76, CN2.A1, CN2.A2, CN2.A3, CN2.A4, CN2.A5, CN2.A6, CN2.A7, CN2.A8, CN2.A9, CN2.A10, CN2.A17, CN2.A18, CN2.B1, CN2.B4, CN2.B7, CN2.B10, CN3.1, CN4.1, CN4.3, CN4.5, CN4.7, CN4.9, CN4.11, J5.1, P0.1, P1.1, Palt0.1, R1.1, R4.2, R5.1, U1.18, U1.31, U1.34, U1.36, U1.39, U1.44, U1.47, U1.48, U1.54, U1.55, U1.59, U1.62, U1.63, U1.65, U2.2, X1.1, X1.2
MCSn: CN1.36, U2.5
MSCK: CN1.24, U2.1
MSI: CN1.26, U2.3
MSO: CN1.34, U2.4
unnamed: C23.1, U1.42
unnamed: C24.1, C25.1, C28.1, U1.33
unnamed: C24.2, C25.2, C29.1, U1.32
unnamed: C31.2, U1.37
unnamed: C32.2, U1.38
unnamed: CN1.1, CN1.2, J7.1
unnamed: CN1.3, U1.30
unnamed: CN1.4, J5.2
unnamed: CN1.5, J3.2
unnamed: CN1.6, J6.1, R4.1, U1.16
unnamed: CN1.7, TP1.1
unnamed: CN1.8, TP6.1
unnamed: CN1.9, CN3.10
unnamed: CN1.11, U1.29
unnamed: CN1.12, CN3.2
unnamed: CN1.13, U1.28
unnamed: CN1.14, CN3.4
unnamed: CN1.15, U1.27
unnamed: CN1.16, CN3.3
unnamed: CN1.17, U1.26
unnamed: CN1.18, CN3.6
unnamed: CN1.19, U1.25
unnamed: CN1.20, CN3.5
unnamed: CN1.23, U1.24
unnamed: CN1.25, U1.23
unnamed: CN1.27, U1.22
unnamed: CN1.28, CN3.8
unnamed: CN1.29, U1.21
unnamed: CN1.30, CN3.7
unnamed: CN1.31, U1.20
unnamed: CN1.35, U1.15
unnamed: CN1.37, U1.14
unnamed: CN1.38, TP5.1
unnamed: CN1.39, U1.13
unnamed: CN1.40, J6.2
unnamed: CN1.41, U1.12
unnamed: CN1.42, TP4.1
unnamed: CN1.43, U1.11
unnamed: CN1.45, U1.10
unnamed: CN1.46, J4.1
unnamed: CN1.47, U1.9
unnamed: CN1.48, TP3.1
unnamed: CN1.49, U1.8
unnamed: CN1.51, U1.7
unnamed: CN1.55, U1.6
unnamed: CN1.57, U1.5
unnamed: CN1.59, U1.4
unnamed: CN1.61, U1.3
unnamed: CN1.63, U1.2
unnamed: CN1.65, U1.1
unnamed: CN1.67, TP2.1, U1.53
unnamed: CN3.9, S1.1
unnamed: CN3.11, S2.1
unnamed: CN3.12, S3.1
unnamed: FB5.2, J8.2
unnamed: J1.2, U1.49
unnamed: J2.2, U1.45
unnamed: J3.1, J4.2, R5.2, U1.19
unnamed: R1.2, U1.41
unnamed: U1.57, X1.3

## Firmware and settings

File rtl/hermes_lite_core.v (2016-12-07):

//
//  Hermes Lite
// 
//
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
// (C) Phil Harman VK6APH, Kirk Weedman KD7IRS  2006, 2007, 2008, 2009, 2010, 2011, 2012, 2013, 2014 
// (C) Steve Haynal KF7O 2014, 2015, 2016

// New VNA mode added by James C. Ahlstrom, N2ADR, 1 December 2016

// This is a port of the Hermes project from www.openhpsdr.org to work with
// the Hermes-Lite hardware described at http://github.com/softerhardware/Hermes-Lite.
// It was forked from Hermes V2.5 but kept up to date to v3.1

module hermes_lite_core(

    input clk50mhz,
    input exp_present,
    input AD9866clkX1,

    input IF_clk,
    input ad9866spiclk,
    input rstclk,
    input EEPROM_clock,
    input IF_locked,

    input extreset,
    output [7:0] leds, 

    // AD9866
    output [5:0] ad9866_pga,
    
`ifdef FULLDUPLEX   
    input [5:0] ad9866_rx,
    output [5:0] ad9866_tx,
    input ad9866_rxsync,
    input ad9866_rxclk,
    output ad9866_txsync,
    output ad9866_txquietn,
`else 
    inout [11:0] ad9866_adio,
    output ad9866_rxen, 
    output ad9866_rxclk,
    output ad9866_txen,
    output ad9866_txclk,
`endif

    output ad9866_sclk,
    output ad9866_sdio,
    input  ad9866_sdo,
    output ad9866_sen_n,

    output ad9866_rst_n,
    output ad9866_mode,

    output exp_ptt_n,

    output [6:0] userout,
    input [2:0] dipsw,

    input cwkey_i,
    output cwkey_o,

    input ptt_i,
 
    // MII Ethernet PHY
    output [3:0]PHY_TX,
    output PHY_TX_EN,              //PHY Tx enable
    input  PHY_TX_CLOCK,           //PHY Tx data clock
    output PHY_TX_CLOCK_out,       //Output for RGMII
    input  [3:0]PHY_RX,     
    input  RX_DV,                  //PHY has data flag
    input  PHY_RX_CLOCK,           //PHY Rx data clock
    output PHY_RESET_N,  
    inout PHY_MDIO,
    output PHY_MDC,

    //12 bit adc's (ADC78H90CIMT)
    output ADCMOSI,                
    output ADCCLK,
    input  ADCMISO,
    output nADCCS
);

// PARAMETERS

// Ethernet Interface
parameter MAC;
parameter IP;
parameter GIGABIT = 0;

// ADC Oscillator
parameter CLK_FREQ = 61440000;

// B57 = 2^57.   M2 = B57/OSC
// 61440000
//localparam M2 = 32'd2345624805;
// 61440000-400
//localparam M2 = 32'd2345640077;
localparam M2 = (CLK_FREQ == 61440000) ? 32'd2345640077 : (CLK_FREQ == 79872000) ? 32'd1804326773 : (CLK_FREQ == 76800000) ? 32'd1876499845 : 32'd1954687338;

// M3 = 2^24 to round as version 2.7
localparam M3 = 32'd16777216;

// Decimation rates
localparam RATE48  = (CLK_FREQ == 61440000) ? 6'd16 : (CLK_FREQ == 79872000) ? 6'd16 : (CLK_FREQ == 76800000) ? 6'd40 : 6'd24;
localparam RATE96  =  RATE48  >> 1;
localparam RATE192 =  RATE96  >> 1;
localparam RATE384 =  RATE192 >> 1;

localparam CICRATE = (CLK_FREQ == 61440000) ? 6'd10 : (CLK_FREQ == 79872000) ? 6'd13 : (CLK_FREQ == 76800000) ? 6'd05 : 6'd08;
localparam GBITS = (CLK_FREQ == 61440000) ? 30 : (CLK_FREQ == 79872000) ? 31 : (CLK_FREQ == 76800000) ? 31 : 31;
localparam RRRR = (CLK_FREQ == 61440000) ? 160 : (CLK_FREQ == 79872000) ? 208 : (CLK_FREQ == 76800000) ? 200 : 192;


// VNA Settings for VNA_SCAN_PC
localparam VNATXGAIN = 6'h10;
localparam DUPRXMAXGAIN = 6'h12;
localparam DUPRXMINGAIN = 6'h06;

// Number of Receivers
parameter NR; // number of receivers to implement
wire [7:0]AssignNR;         // IP address read from EEPROM
assign AssignNR = NR;

// Number of transmitters Be very careful when using more than 1 transmitter!
parameter NT = 1;

// Experimental Predistort On=1 Off=0
parameter PREDISTORT = 0;

wire FPGA_PTT;

parameter M_TPD   = 4;
parameter IF_TPD  = 2;

parameter  Hermes_serialno = 8'd32;     // Serial number of this version
localparam Penny_serialno = 8'd00;      // Use same value as equ1valent Penny code 
localparam Merc_serialno = 8'd00;       // Use same value as equivalent Mercury code

localparam RX_FIFO_SZ  = 4096;          // 16 by 4096 deep RX FIFO
localparam TX_FIFO_SZ  = 1024;          // 16 by 1024 deep TX FIFO  
localparam SP_FIFO_SZ = 2048;           // 16 by 8192 deep SP FIFO, was 16384 but wouldn't fit


localparam bit [0:19][8:0] initarray_nointerpolation = {
    // First bit is 1'b1 for write enable to that address
    {1'b1,8'h80}, // Address 0x00, enable 4 wire SPI
    {1'b0,8'h00}, // Address 0x01,
    {1'b0,8'h00}, // Address 0x02, 
    {1'b0,8'h00}, // Address 0x03, 
    {1'b1,8'h00}, // Address 0x04, // No multiply of oscillator for no interpolation
    {1'b0,8'h00}, // Address 0x05, 
    {1'b1,8'h00}, // Address 0x06, // No divide down for FPGA clock
    {1'b1,8'h21}, // Address 0x07, Initiate DC offset calibration and RX filter on
    {1'b1,8'h4b}, // Address 0x08, RX filter f-3db at ~34 MHz after scaling
    {1'b0,8'h00}, // Address 0x09, 
    {1'b0,8'h00}, // Address 0x0a, 
    {1'b1,8'h20}, // Address 0x0b, RX gain only on PGA
    {1'b1,8'h81}, // Address 0x0c, TX twos complement and interpolation factor
    {1'b1,8'h01}, // Address 0x0d, RT twos complement 
    {1'b0,8'h01}, // Address 0x0e, Enable/Disable IAMP 
    {1'b0,8'h00}, // Address 0x0f,     
    {1'b0,8'h84}, // Address 0x10, Select TX gain
    {1'b1,8'h00}, // Address 0x11, Select TX gain
    {1'b0,8'h00}, // Address 0x12, 
    {1'b0,8'h00}  // Address 0x13,     
};

localparam bit [0:19][8:0] initarray_2xosc = {
    // First bit is 1'b1 for write enable to that address
    {1'b1,8'h80}, // Address 0x00, enable 4 wire SPI
    {1'b0,8'h00}, // Address 0x01,
    {1'b0,8'h00}, // Address 0x02, 
    {1'b0,8'h00}, // Address 0x03, 
    {1'b1,8'h16}, // Address 0x04, 
    {1'b0,8'h00}, // Address 0x05, 
    {1'b0,8'h00}, // Address 0x06,
    {1'b1,8'h21}, // Address 0x07, Initiate DC offset calibration and RX filter on
    {1'b1,8'h4b}, // Address 0x08, RX filter f-3db at ~34 MHz after scaling
    {1'b0,8'h00}, // Address 0x09, 
    {1'b0,8'h00}, // Address 0x0a, 
    {1'b1,8'h20}, // Address 0x0b, RX gain only on PGA
    {1'b1,8'h41}, // Address 0x0c, TX twos complement and interpolation factor 
    {1'b1,8'h01}, // Address 0x0d, RT twos complement 
    {1'b0,8'h01}, // Address 0x0e, Enable/Disable IAMP 
    {1'b0,8'h00}, // Address 0x0f,     
    {1'b0,8'h84}, // Address 0x10, Select TX gain
    {1'b1,8'h00}, // Address 0x11, Select TX gain
    {1'b0,8'h00}, // Address 0x12, 
    {1'b0,8'h00}  // Address 0x13,     
};
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

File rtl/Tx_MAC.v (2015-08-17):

//
//  HPSDR - High Performance Software Defined Radio
//
//  Metis code. 
//
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

//  Tx_MAC - Copyright 2009, 2010, 2011  Phil Harman VK6APH






//----------------------------------------
//   Tx_MAC - Interface to PHY
//----------------------------------------

/* 
	The format of the data to the PHY at 100T is as follows
	
	                  +----+    +----+    +----+    +----+    +----+    +----+    +----+    +----+    
	PHY_Tx_clock    --+    +----+    +----+    +----+    +----+    +----+    +----+    +----+  		25MHz
	
					      	  +-----------------------------------------------------------------
	Tx_CTL     ------------+
	
	                       +---------+---------+---------+---------+---------+---------+---------+
	TD					        +---------+---------+---------+---------+---------+---------+---------+
	
	nibble (100T)          3:0       7:4       3:0       7:4       3:0       7:4       3:0       7:4
	


	
 
    At 1000T the 3:0 nibble is sent on the positive edge of Rx_clock and 7:4 on the negative edge vis:
    
    
    	             +----+    +----+    +----+    +----+    +----+    +----+    +----+    +----+    
	PHY_Tx_clock    +    +----+    +----+    +----+    +----+    +----+    +----+    +----+  		125MHz
		
						        +-----------------------------------------------------------------
	Tx_CTL     ------------+
	
	                       +----+----+----+----+----+----+----+----+----+----+----+----+----+----+
	TD					        +----+----+----+----+----+----+----+----+----+----+----+----+----+----+
	
	nibble (100T)          3:0  7:4  3:0  7:4  3:0  7:4  3:0  7:4  3:0  7:4  3:0  7:4  3:0  7:4  3:0 
	
	
	Operation is as follows:
	
	The transmit state machine loops looking for either an APR request, ping request or the PHY_Tx fifo having > 1023
	bytes in it. The latter conditions indicates a UDP/IP send request.
	
	ARP:
	This causes a read of a predetermed sequence of bytes that are addressed in sequence by a state machine.
	During the procees the CRC32 calculation is started and appended at the end of the sequence of bytes.
	
	
	PING:
	This first calculates the ping checksum, reads a predetermend sequence of bytes that are addressed in sequence
	then appends the original ping data obtained by the Rx_MAC. During the procees the CRC32 calculation is started
	and appended at the end of the ping data.
	
	
	UDP/IP:
	This causes a read of a predetermed sequence of bytes that are addressed in sequence by a state machine.
	1024 bytes from the PHY_Tx fifo are then appended. During the procees the CRC32 calculation is started
	and appended at the end of the fifo bytes.
	
	NOTE: This code makes use of a large number of states. Each packet that we send uses it own dedicated state
	machine. It is possible to combine common elements of the code e.g. preamble. However, doing so does not 
	reduced the size of the code since Quartus is able to optimise away the duplicated states. The use of individual 
	state machines had been used to make the code more readable.
	
	Change log:
	

	2011 Mar   11    	- Send DHCP server IP address as an option in DHCP_request.
	     Apr    2    	- Reset sequence number when not running rather than when Discovery received. 
							- Add run state and Metis software version to Discovery reply.
					3    	- Add wide band spectrum and on/off enable
	     May   13     - Added independant serial number for wide bandscope data.

*/

module Tx_MAC (Tx_clock, Tx_clock_2, IF_rst, Send_ARP,ping_reply,
			   PHY_Tx_data, PHY_Tx_rdused, ping_data, LED, Tx_fifo_rdreq,
			   Tx_CTL, ARP_sent, ping_sent, TD, DHCP_discover, DHCP_discover_sent,
			   This_MAC,SIADDR, DHCP_request,
			   DHCP_request_sent, METIS_discovery, PC_IP, PC_MAC,
			   Port, This_IP, METIS_discover_sent, ARP_PC_MAC, ARP_PC_IP,
			   Ping_PC_MAC, Ping_PC_IP, Length, speed_100T, Tx_reset, run, wide_spectrum,
			   IP_valid, DHCP_IP, DHCP_MAC, DHCP_request_renew, DHCP_request_renew_sent,
			   Hermes_serialno,
			   sp_fifo_rddata, sp_fifo_rdreq, sp_fifo_rdempty, sp_fifo_rdused, have_sp_data,
				 AssignIP, IDHermesLite, AssignNR);
			   
			   
			   
input  Tx_clock;					// 25MHz for 100T
input  Tx_clock_2;				// clock/2
input  IF_rst;						// reset signal
input  Send_ARP;					// high to send ARP response
input  ping_reply;				// high to send ping response
input  [7:0]PHY_Tx_data;		// data to send to PHY
input  [10:0]PHY_Tx_rdused;	// data available in Tx fifo  
input  [7:0]ping_data[0:59];   // data to send back 	
input  DHCP_discover; 			// high when requested
input  [47:0]This_MAC;			// MAC address of this Metis board
input  [31:0]SIADDR;				// IP address of server that provided IP address
input  DHCP_request;				// high when request required
input  METIS_discovery;			// high when reply required
input  [31:0]PC_IP;				// IP address of the PC we are connecting to
input  [47:0]PC_MAC;				// MAC address of the PC we are connecting to
input  [15:0]Port;			   // Port on the PC we are sending to
input  [31:0]This_IP;			// IP address provided by PC or DHCP at start up
input  [47:0]ARP_PC_MAC;		// MAC address of PC requesting ARP
input  [31:0]ARP_PC_IP;			// IP address of PC requesting ARP
input  [47:0]Ping_PC_MAC;		// MAC address of PC requesting ping
input  [31:0]Ping_PC_IP;		// IP address of PC requesting ping
input  [15:0]Length;				// Lenght of packet - used by ping
input  speed_100T;				// high for 100T,low for 1000T       ************  check
input  Tx_reset;					// high to prevent I&Q data being sent
input  run;							// high to enable data to be sent
input  wide_spectrum;			// high to enable wide spectrum data to be sent
input  IP_valid;					// high when we have a valid IP address 
input  [31:0]DHCP_IP;			// IP address of DHCP server
input  [47:0]DHCP_MAC;			// MAC address of DHCP server 
input  DHCP_request_renew;		// set when renew required
input  [7:0]Hermes_serialno;	// Hermes code version
input  [7:0]sp_fifo_rddata;		// raw ACD data from Mercury for wide bandscope
input  sp_fifo_rdempty;			// SP_fifo read empty
input  [12:0]sp_fifo_rdused;	// SP_fifo contents
input  have_sp_data;				// high when sp_fifo is full.
input  [31:0]AssignIP;			// IP address read from EEPROM
input IDHermesLite;
input  [7:0]AssignNR;

output LED;							// show MAC is doing something!
output Tx_fifo_rdreq;			// high to indicate read from Tx fifo required
output Tx_CTL;						// high to enable write to PHY
output ARP_sent;					// high indicates ARP has been sent
output ping_sent;					// high indicates ping reply has been sent
output [3:0]TD;					// nibble to send to PHY
output DHCP_discover_sent;		// high when has been sent
output DHCP_request_sent;       // high when has been sent
output METIS_discover_sent;		// high when has been sent ** pulse
output DHCP_request_renew_sent;	// high when has been sent
output sp_fifo_rdreq;			// SP_fifo read require signal
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

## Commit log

2014-04-20 Added more assembly info
2014-04-20 Added "Staying Well Grounded"
2014-08-25 Schematic rev 1.1a
    [ad9866.sch]
2014-08-28 Added modified and pci36
    [ad9866.kicad_pcb]
2014-09-01 Before library and name changes
    [ad9866.sch]
2014-09-02 Rev 1.1b schematic, footprint library, and library cleanup
    [ad9866.kicad_pcb, ad9866.sch, hermeslite.kicad_pcb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]
2014-09-08 RTL cleanup and upgrade to Quartus 14.0
    [hermeslite.kicad_pcb, hermeslite.sch]
2014-10-01 Intermediate save before move of PCIe connector
    [hermeslite.kicad_pcb, hermeslite.sch]
2014-10-05 Commit before silkscreen cleanup
    [hermeslite.kicad_pcb, hermeslite.sch]
2014-10-05 Version 1.2 for review
    [hermeslite.kicad_pcb, hermeslite.sch]
2014-10-08 Updated BOM, renumbered a few references
    [bom.xls, hermeslite.kicad_pcb, hermeslite.sch]
2014-10-09 iTead Studio submission
    [hermeslite.kicad_pcb, hermeslite.sch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]
2014-10-20 Added RF frontend template and basic
    [bom.xls, frontend.kicad_pcb, frontend.sch]
2014-10-24 Added WaveShare2BeMicroCV swizzle board
    [bom.xls, waveshare.kicad_pcb, waveshare.sch]
2014-11-27 Updated basic frontend
    [frontend.kicad_pcb, frontend.sch]
2014-12-09 Added revision 1.21
    [frontend.kicad_pcb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]
2014-12-09 updated schematic
2014-12-18 Updated pcb BOM and kit BOM
    [bom.xls, kit.xls]
2015-01-09 Fix for bom
    [bom.xls]
2015-01-12 Updated frontend schematic to match build instructions
    [frontend.sch]
2015-01-16 Support for 384kHz and fix for TX sideband spurs
    [hermes_lite_core.v]
2015-01-17 WIP on filtering
2015-01-21 Updated schematics for user[6:0]
    [frontend.sch, hermeslite.sch]
2015-01-22 Added UNL2003 and connectors
    [$frontend.sch]
2015-01-25 Revert "Added UNL2003 and connectors"
    [$frontend.sch, frontend.kicad_pcb, frontend.sch]
2015-01-26 Release 20150125, test mode works again, ADC overload to software, tweaks to AGC
2015-02-04 Recalculate for 12-bit RX path, overload hooked up tolonger LEDs, PTT matches Hermes
2015-02-06 Gain to match PowerSDR, AGC gain tracks manual gain setting, increased timeout on AGC, proper inversion of ADC overload
2015-02-06 Updated frontend xls with kit binocular core part
    [bom.xls]
2015-02-11 Added patches to Hermes v3.1, target CV C8 device, constrained some external FPGA to ADC pins
2015-02-16 Add TX Drive level, Hermes-Lite board ID, increased user IO drive, tweaked frequency calibration
2015-02-18 20150217: Some timing fixes, increased current on ptt
2015-03-02 Work on timing bug
    [hermes_lite_core.v]
2015-03-16 Added first 3D printer files
    [hermes_lite_v2.scad, hermes_lite_v2.stl]
2015-03-26 Updated BOM with new oscillator part number
    [bom.xls, kit.xls]
2015-03-30 3RX on SDK, constant current TX gain adjustment, no ASMII
2015-04-13 Added support for ADC measurements via SPI
2015-05-14 Added support for 73.728 oscillator
    [hermes_lite_core.v]
2015-05-18 20150517: 73.728 support, multiple MAC, SPI ADC, refactoring
2015-05-24 Update to v1.22
    [frontend.gbl, frontend.gbo, frontend.gbs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]
2015-05-24 Added gerber for v1.22
    [hermeslite.gbl, hermeslite.gbo, hermeslite.gbs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]
2015-06-14 Changed address for RX8 to not collide with existing protocol
    [hermes_lite_core.v]
2015-07-05 Added Power Amplifiers
2015-07-07 Updated frequency information
    [bom.xls, kit.xls]
2015-07-28 Fix for test bug in full duplex
    [hermes_lite_core.v]
2015-08-17 Gigabit cleanup, DHCP fixes
    [Tx_MAC.v, ethernet.v, hermes_lite_core.v]
2015-09-08 Added new test frontend
    [frontend.kicad_pcb, frontend.sch]
2015-09-14 Updated Schematic, floorplanning
    [frontend.kicad_pcb, frontend.sch]
2015-09-21 New frontend board
    [frontend.kicad_pcb, frontend.sch]
2015-09-21 Added gerber
    [frontend-B_Cu.gbr, frontend-B_SilkS.gbr, frontend-Edge_Cuts.gbr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]
2015-09-21 Proper pin placement
2015-10-13 Pure signal support, CVA9 fullduplex, icmp destination unreachable fix, external ptt, v2 frontend gerber, spectrum analyzer scripts
    [frontend-B_Cu.gbr, frontend-B_SilkS.gbr, frontend-Edge_Cuts.gbr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]
2015-10-18 Fix to keep host IP and MAC
    [hermes_lite_core.v]
2016-01-18 Program parameters for SPI, RX support for 79.872, work on better timing closure
2016-02-11 Added v1.3 frontend from Jim
    [frontend-B.Cu.gbl, frontend-B.Mask.gbs, frontend-B.SilkS.gbo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]
2016-02-14 Support to disable IAMP, fix in ad9866 for TX level bug
    [hermes_lite_core.v]
2016-04-22 Added frontend V1.42 from Jim
    [frontend.csv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]
2016-11-24 Switch to 2.x

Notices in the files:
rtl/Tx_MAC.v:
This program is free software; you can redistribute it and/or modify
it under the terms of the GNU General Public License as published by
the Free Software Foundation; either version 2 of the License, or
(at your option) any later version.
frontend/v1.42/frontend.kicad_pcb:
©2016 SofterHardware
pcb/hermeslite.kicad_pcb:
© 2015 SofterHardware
